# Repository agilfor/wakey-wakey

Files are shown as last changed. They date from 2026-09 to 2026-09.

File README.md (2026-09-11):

# wakey-wakey

wakey-wakey is a simple alarm clock built on a Seeed Studio XIAO ESP32C3. It runs on C++.

## Features

- TFT Display
- 4 buttons
- Battery or USB-C power
- Deep sleep
- Buzzer
- Alarms (WIP)
- Wi-Fi config (WIP)
- Wi-Fi time sync (WIP)

## CAD

The goal of this model was to make it as symmetrical as possible and as minimalistic as possible. The idea is for it to look simple and be functional as an alarm clock should be.

The current design was made in Onshape. It has screwholes for the PCB, a slot for the TFT display, holes for the buzzer sound, a gap for a USB-C cable, and a top cover with the functions of the buttons engraved.

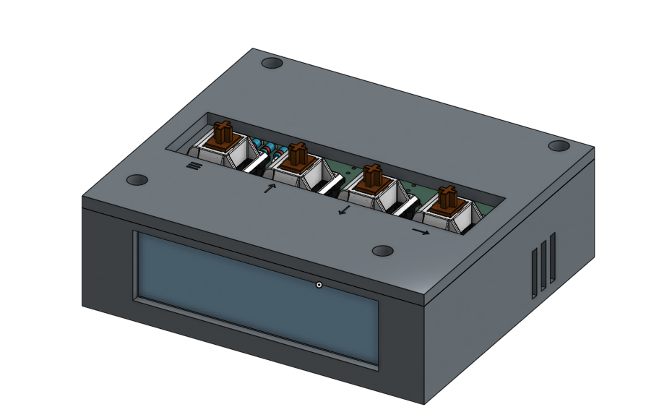
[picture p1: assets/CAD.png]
Current CAD model


## PCB

My PCB was made in KiCad. I went a bit more crazy with this than with the CAD, so it took a while. It has 4 keys Charlieplexed to 3 pins, a buzzer, and a TFT display with all pins connected. Additionally, it has been designed with battery functionality in mind. It has a pin header to connect a battery cell to the ESP32C3 VBAT and GND pins (requires some soldering), and uses a nifty voltage divider (with two 220kΩ resistors) connected to an analog pin to allow for battery level measurements. Though these parts fall outside of the standard kit, I have them at home so decided to add them because it's cool and because why not ¯\\\_(ツ)\_/¯

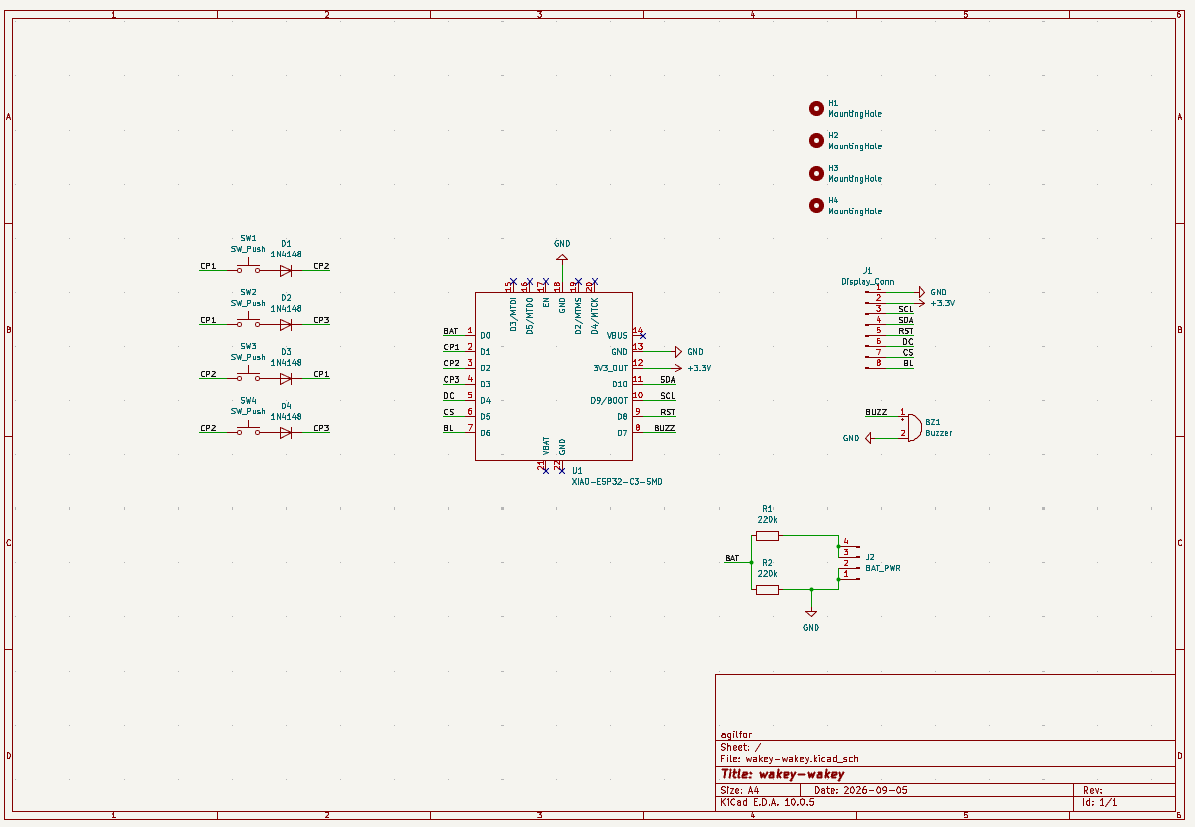
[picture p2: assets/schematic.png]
Current schematic


This is my current schematic. It uses charlieplexing to wire the keys (which is how I made space for the battery pin). The downside is it means I need to write more firmware to make it work. Other than that it's not very complicated. There are technically some wires missing (VBAT, GND, and the whole BAT_PWR block) as those require soldering. [More info about the battery trick](https://forum.seeedstudio.com/t/battery-voltage-monitor-and-ad-conversion-for-xiao-esp32c/267535).

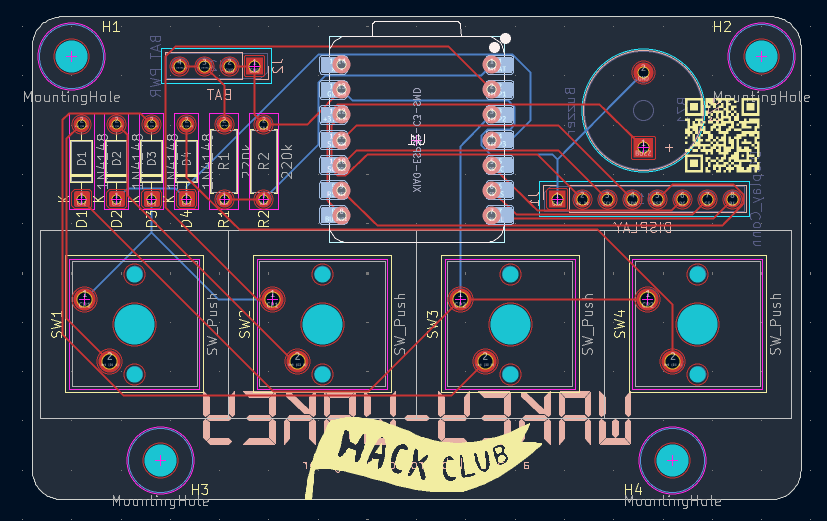
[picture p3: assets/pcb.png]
Current PCB


This is my PCB. The routing wasn't particularly difficult, but I had fun with it. I mostly ended up making life difficult for myself by trying to make it as small as possible. Also, I spent way too long on the silkscreen designs but no regrets :)

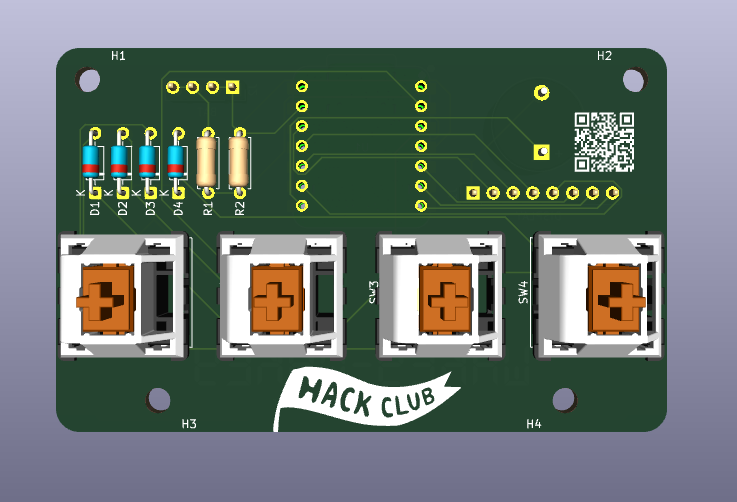
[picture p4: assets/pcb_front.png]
PCB CAD Model (Front)

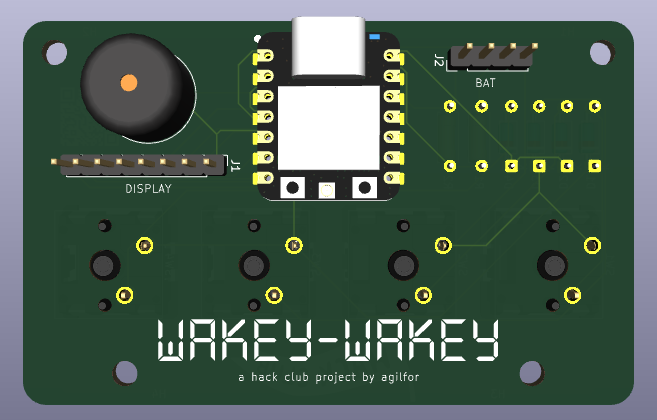
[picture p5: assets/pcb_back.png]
PCB CAD Model (Back)


### Wiring/Soldering

Due to the mount style of the XIAO ESP32C3, it is not possible to easily connect the battery pads under the microcontroller to the PCB (technically this is possible using a SMD mount, but it is a pain and much simpler to do some soldering with a DIP mount). The 4 pin male header is the connection of the battery to the microcontroller. It has 4 pins as it requires two pins for VCC and two for GND (connection to the battery cell and connection to the microcontroller). For a more detailed explanation please consult the `battery.md` doc.

## Firmware Overview

The wakey-wakey uses C++ firmware for everything. Currently it supports deep sleep and waking on button press. It should also be able to draw to the TFT display.

Support still needs to be added for all the Wi-Fi functionalities, as well as the alarm, 24H time view toggle, and more. This will be done post-assembly, as some testing needs to be done with the charlieplexed keys before making the script more complicated than it already is.

There will probably be more changes as well to the firmware after all this, but that remains TBD.

## BOM

- 1x Seeed Studio XIAO ESP32C3
- 4x Cherry MX switches
- 4x White blank DSA keycaps
- 1x 2.25in TFT Display
- 1x 3.3V Piezo buzzer
- 1x 2.54mm 8 pin male header
- 8x 20cm female-female jumper wires
- 4x Through-hole 1N4148 Diodes
- 8x M3x5x4 Heatset inserts
- 4x M3x8mm Screws
- 4x M3x16mm Screws

Extra:

- 2x 220kΩ resistors
- 1x 4 pin male header
- LIR2450 battery cell 
- LIR2450 battery holder

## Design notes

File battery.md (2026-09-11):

# Battery Wiring Explained

The idea of the battery wiring stems from a section of the [Seeed Studio XIAO ESP32C3 docs](https://wiki.seeedstudio.com/XIAO_ESP32C3_Getting_Started/#check-the-battery-voltage). The idea is that a battery can be wired to the battery pads, with the limitation that the ESP32C3 does not natively support monitoring the battery voltage. A [post by msfujino](https://forum.seeedstudio.com/t/battery-voltage-monitor-and-ad-conversion-for-xiao-esp32c/267535) details how this can be done using the A0 pin and a voltage divider. 

The solution presented by msfujino has been implemented in the design of wakey-wakey, but it requires soldering. Normally, it would be possible to wire directly from battery -> ESP32C3, but with the resistors for the voltage dividers it becomes more complicated and we end up with battery -> PCB -> ESP32C3. This is shown in the diagram below.

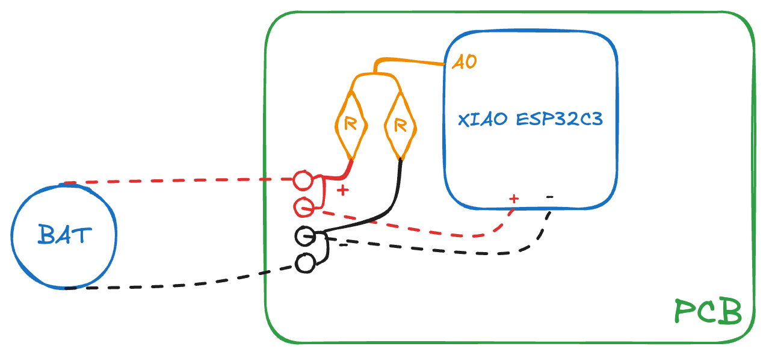
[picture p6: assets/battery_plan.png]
The diagram of the battery wiring


The dotted lines indicated wiring/soldering that cannot be incorporated into the PCB. Though it would technically be possible to solder the resistors directly onto the ESP32C3 microcontroller, I find it to be a much cleaner solution to put it on the PCB as shown above. Electrically, the two circuits are equivalent so it does not make a difference for the functionality of the design.

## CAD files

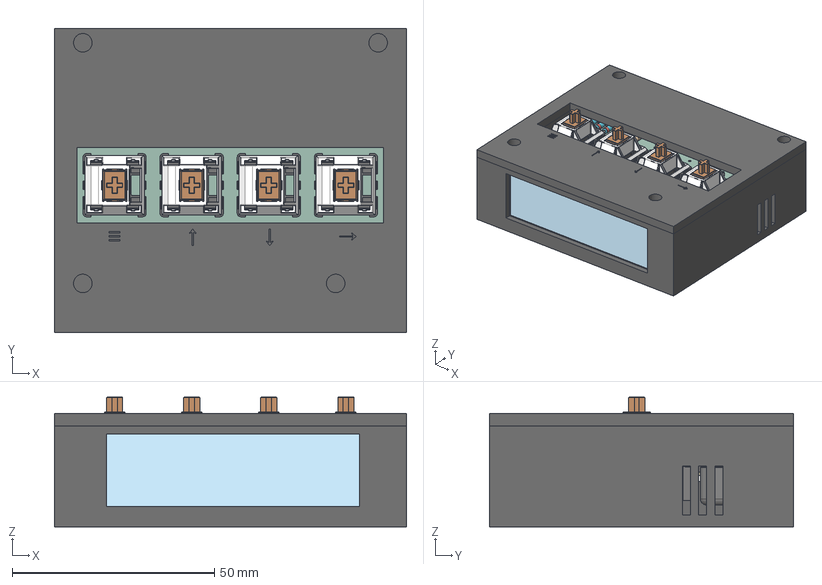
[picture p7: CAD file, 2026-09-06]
CAD/wakey-wakey_ASSEMBLED.step
87.0 x 75.1 x 32.1 mm
QFN32G-0.5-5X5MM:U4
D_DO-35_SOD27_P7.62mm_Horizontal_2 x 2
R0201:R4
C0201:C50
C0201:C14
D_DO-35_SOD27_P7.62mm_Horizontal_1 x 2
Pin_2_1
Spring_3
Pins 0-6 x 7
R0201:R6
R0201:R9
C0201:C54
C0201:C45
C0201:C15
C0201:C12
D_DO-35_SOD27_P7.62mm_Horizontal x 2
Clicker_1
D_DO-35_SOD27_P7.62mm_Horizontal_3 x 2
Pin_1_3
Pins 7-13 x 7
R0201:R8
R0201:R32
C0201:C1
C0201:C44
LED-0402:CHG
C0201:C11
SOT-25:U1
Clicker
Lower_Housing_2
R_Axial_DIN0207_L63mm_D25mm_P762mm_Horizontal_1
Stem_3
PinSocket_1x02_P2.54mm_Vertical
R0201:R10
Spring
C0201:C2
L0201:L1
Pin_2
Upper_Housing_2
PinSocket_1x08_P2.54mm_Vertical
C0201:C23
Pin_1
C0201:C5
PMOS_1.0*0.6*0.35MM:Q1
Stem
Pin_1_2
EMF Shield x 2
R0201:R1
C0201:C40
Upper_Housing
C0201:C7
X2-SMD-1.6X1.0X0.5MM:X2
Lower_Housing
Spring_2
R0201:R22
C0201:C42
C0201:C9
Lower_Housing_3
Upper_Housing_1
Lower_Housing_1
Stem_1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

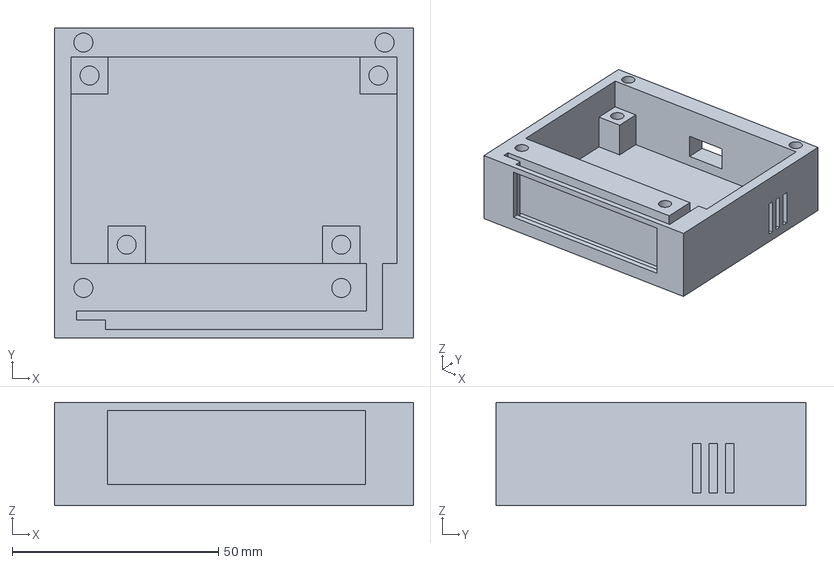
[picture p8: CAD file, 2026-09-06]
production/body.step
87.0 x 75.1 x 25.0 mm

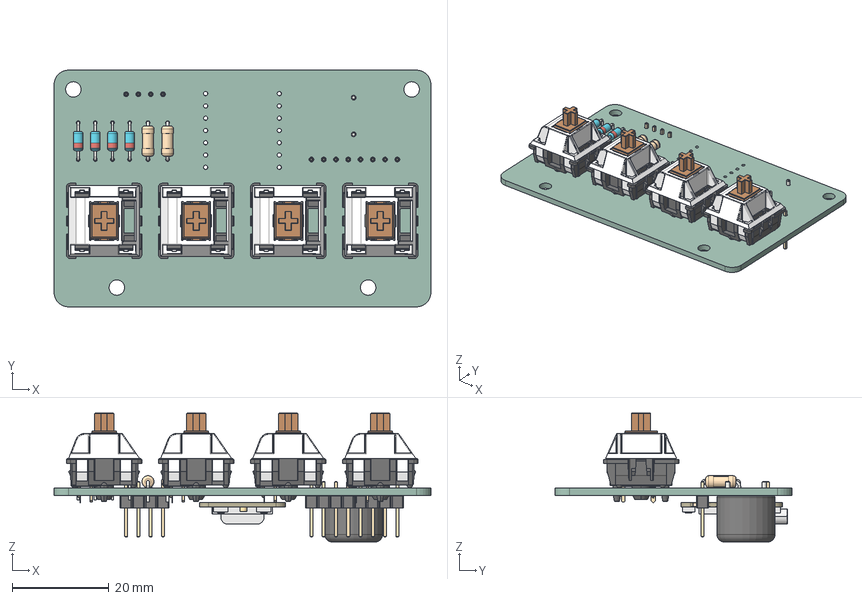
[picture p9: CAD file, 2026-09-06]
CAD/pcb.step
78.0 x 49.0 x 26.7 mm
Lower_Housing x 4
Upper_Housing x 4
Stem x 4
Pin_1 x 4
Pin_2 x 4
Spring x 4
Clicker x 4
D_DO-35_SOD27_P7.62mm_Horizontal x 4
R_Axial_DIN0207_L63mm_D25mm_P762mm_Horizontal x 2
PinHeader_1x04_P254mm_Vertical
Buzzer_12x95RM76
PinHeader_1x08_P254mm_Vertical
EMF Shield
Pins 0-6
Pins 7-13
JTAG pads
BAT pads
Board:1
R0201:R1
R0201:R2
R0201:R22
R0201:R31
R0201:R32
R0201:R9
R0201:R3
R0201:R4
R0201:R5
R0201:R6
R0201:R7
R0201:R8
R0201:R10
F0603:F1
C0201:C23
C0201:C39
C0201:C40
C0201:C41
C0201:C42
C0201:C43
C0201:C44
C0201:C45
C0201:C48
C0201:C50
C0201:C53
C0201:C54
C0201:C4
C0201:C1
C0201:C2
C0201:C3
C0201:C5
C0201:C6
C0201:C7
C0201:C8
C0201:C9
C0201:C10
C0201:C11
C0201:C12
C0201:C13
C0201:C14
C0201:C49
C0201:C15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

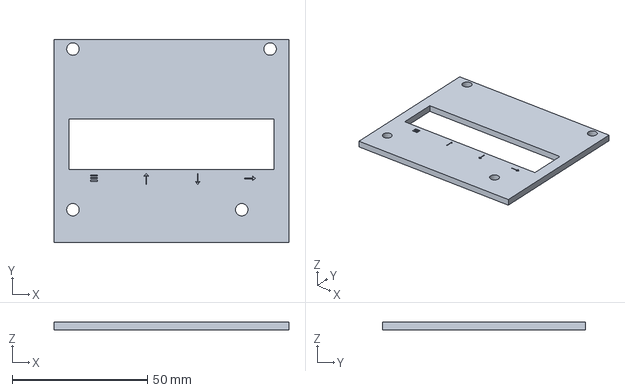
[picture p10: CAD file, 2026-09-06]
production/top.step
87.0 x 75.1 x 3.00 mm

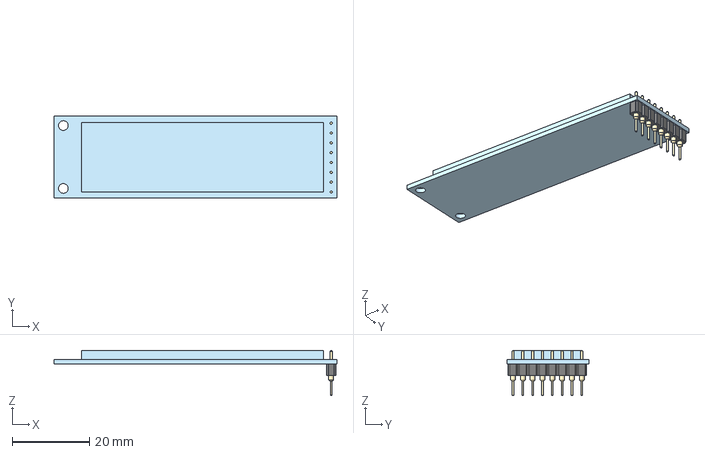
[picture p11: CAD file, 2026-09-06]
CAD/display.step
73.2 x 21.1 x 11.8 mm
8 pin header v1_1 x 9

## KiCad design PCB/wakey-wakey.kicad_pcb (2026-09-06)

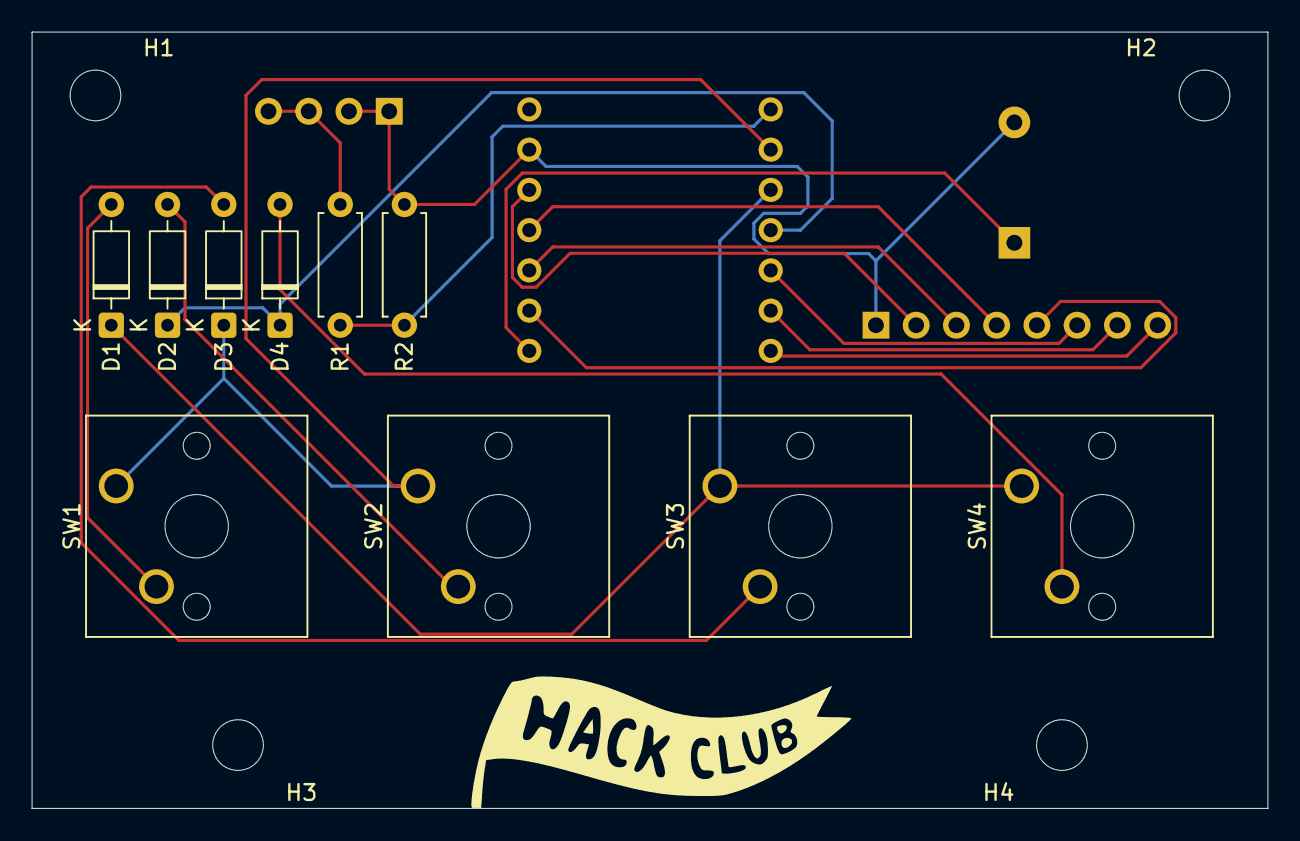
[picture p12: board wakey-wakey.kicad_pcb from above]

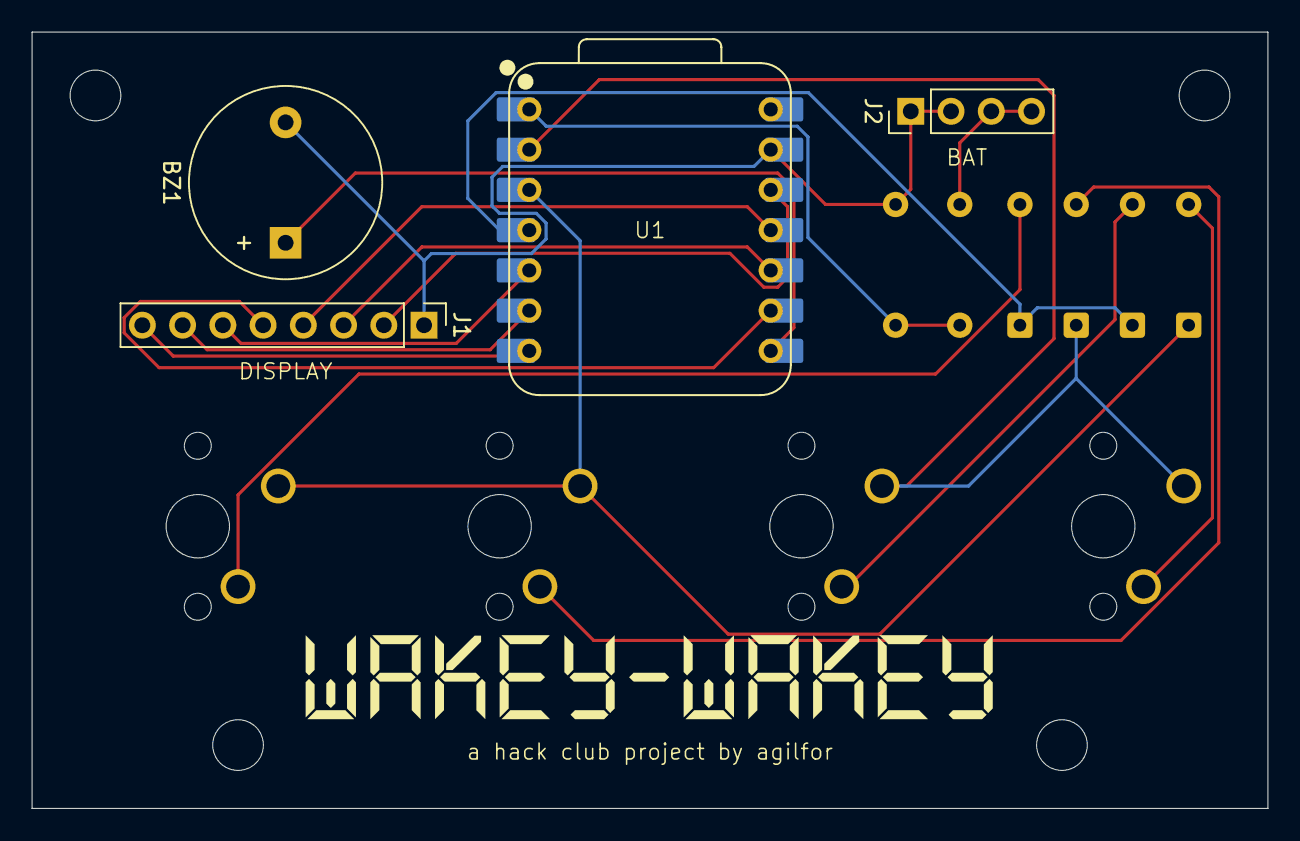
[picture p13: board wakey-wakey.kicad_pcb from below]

Board: 2 copper layers, 78.0 x 49.0 mm, 18 parts (4 on the bottom side), 18 nets.

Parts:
BZ1: Buzzer; Buzzer_12x9.5RM7.6
D1, D2, D3, D4: 1N4148; D_DO-35_SOD27_P7.62mm_Horizontal
H1, H2, H3, H4: MountingHole; MountingHole_3.2mm_M3
J1: Display_Conn; PinHeader_1x08_P2.54mm_Vertical
J2: BAT_PWR; PinHeader_1x04_P2.54mm_Vertical
R1, R2: 220k; R_Axial_DIN0207_L6.3mm_D2.5mm_P7.62mm_Horizontal
SW1, SW2, SW3, SW4: SW_Push; SW_Cherry_MX_1.00u_PCB
U1: XIAO-ESP32-C3-SMD; XIAO-ESP32-C3-DIP

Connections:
+3.3V: J1.2, U1.12 (3V3_OUT)
/BAT: R1.1, R2.1, U1.1 (D0)
/BL: J1.8, U1.7 (D6)
/BUZZ: BZ1.1 (+), U1.8 (D7)
/CP1: D3.1 (K), SW1.1, SW2.1, U1.2 (D1)
/CP2: D1.1 (K), SW3.1, SW4.1, U1.3 (D2)
/CP3: D2.1 (K), D4.1 (K), U1.4 (D3)
/CS: J1.7, U1.6 (D5)
/DC: J1.6, U1.5 (D4)
/RST: J1.5, U1.9 (D8)
/SCL: J1.3, U1.10 (D9/BOOT)
/SDA: J1.4, U1.11 (D10)
GND: BZ1.2 (-), J1.1, J2.1, J2.2, R2.2, U1.13 (GND)
unnamed: D1.2 (A), SW1.2
unnamed: D2.2 (A), SW2.2
unnamed: D3.2 (A), SW3.2
unnamed: D4.2 (A), SW4.2
unnamed: J2.3, J2.4, R1.2

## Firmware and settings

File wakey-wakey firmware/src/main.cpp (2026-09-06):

#include <Adafruit_GFX.h>
#include <Adafruit_ST7789.h>
#include <SPI.h>
#include <time.h>

#define BAT A0
#define BUZZ 20

#define CP1 GPIO_NUM_3
#define CP2 GPIO_NUM_4
#define CP3 GPIO_NUM_5

#define TFT_SCLK 9    // SCL
#define TFT_MOSI 10   // SDA
#define TFT_RST 8
#define TFT_DC 6
#define TFT_CS 7
#define TFT_BL 21

const String days[7] = {"SUN", "MON", "TUE", "WED", "THU", "FRI", "SAT"};
const String months[12] = {"JAN", "FEB", "MAR", "APR", "MAY", "JUN", "JUL", "SEP", "OCT", "NOV", "DEC"};

Adafruit_ST7789 tft = Adafruit_ST7789(TFT_CS, TFT_DC, TFT_MOSI, TFT_SCLK, TFT_RST);

float get_battery_level() {
  uint32_t Vbatt = 0;
  for (int i = 0; i < 16; i++) {
    Vbatt = Vbatt + analogReadMilliVolts(BAT);
  }
  float Vbattf = 2 * Vbatt / 16 / 1000.0;
  return Vbattf;
}

void draw_clock(Adafruit_ST7789 tft, tm time, float vbatt) {
  tft.fillScreen(ST77XX_BLACK);
  tft.setCursor(5, 5);
  tft.setTextSize(6);
  tft.setTextColor(ST77XX_WHITE);
  tft.printf("%s %i %s %i", days[time.tm_wday], time.tm_mday, months[time.tm_mon], 1990 + time.tm_year);
  tft.setCursor(5, 250);
  tft.printf("BAT: %.2f%", vbatt);

  tft.setCursor(20, 50);
  tft.setTextSize(50);
  tft.printf("%i:%i", time.tm_hour, time.tm_min);
}

void setup() {
  gpio_hold_dis(CP2);
  gpio_deep_sleep_hold_dis();

  Serial.begin(115200);

  pinMode(BAT, INPUT);

  pinMode(TFT_BL, OUTPUT);
  digitalWrite(TFT_BL, LOW); 

  tft.init(76, 284);
  tft.invertDisplay(false);
  tft.setRotation(1);
  tft.fillScreen(ST77XX_BLACK);
  Serial.println("TFT Initialized!");
  tft.setCursor(0,0);

  tft.setTextColor(ST77XX_WHITE);
  tft.setTextSize(20);
  tft.setCursor(20,0);
  
  struct tm timeinfo;
  if (!getLocalTime(&timeinfo)) {
    tft.print("WAKEY-WAKEY");
    timeinfo.tm_hour = 0;
    timeinfo.tm_min = 0;
    timeinfo.tm_sec = 0;
    timeinfo.tm_isdst = false;
    timeinfo.tm_mday = 1;
    timeinfo.tm_mon = 0;
    timeinfo.tm_wday= 1;
    timeinfo.tm_yday= 0;
    delay(2000);
  }

  draw_clock(tft, timeinfo, get_battery_level());
  delay(5000);

  pinMode(CP1, INPUT);
  pinMode(CP3, INPUT);
  pinMode(CP2, OUTPUT);
  digitalWrite(CP2, HIGH);
  gpio_hold_en(CP2);

  uint64_t pinBitmask = (1ULL << CP3);
  esp_deep_sleep_enable_gpio_wakeup(pinBitmask, ESP_GPIO_WAKEUP_GPIO_HIGH);

  gpio_deep_sleep_hold_en();

  digitalWrite(TFT_BL, LOW);

  esp_deep_sleep_start();

}

void loop() {
  // work in progress
  // will only be used for when active config is being done
}

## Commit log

2026-09-06 Finished CAD
    [body.step, display.step, top.step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]
2026-09-06 Improvements to PCB and CAD export
    [pcb.step, wakey-wakey.kicad_pcb, wakey-wakey.kicad_sch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]
2026-09-11 Added docs for battery wiring
